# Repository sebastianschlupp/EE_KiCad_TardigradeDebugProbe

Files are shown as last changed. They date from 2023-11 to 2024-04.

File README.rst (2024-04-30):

============
Tardigrade Marine Debug Probe
============

Revision 0.1
============

Required Hand Modifications
~~~~~~~~~~~~~~~~~~~~~~~~~~~

Replace U203 1.8V LDO with 3.3V LDO (LT1962EMS8-1.8 with LT1962EMS8-3.3)

Test Results
------------
  
✅ Voltage outputs OK: VUSB and 1V8

✅ SWD interface OK: connected and successfully erased using J-Link Segger and J-Flash Lite

✅ LEDs OK: VBUS; DBG_LED0; DBG_LED1; VCC; TGT_RESET (remark TGT_RESET led is on when reset is high so inactive ... might want to consider inverting LED in the future)

❌ USB interface not working at 1.8V: please see SAMD21 datasheet chapter 37.15: "The operating voltages must be 3.3V (Min. 3.0V, Max. 3.6V)."

✅ USB interface working at 3.3V

✅ Flashing using west and pyOCD working

Planned Design Changes
----------------------

- Replace LT1962-1.8 with a 3.3V regulator. Also look for a cheaper option since the LT part is around 5€
- Check BOM and investigate need for alternatives (optimise for availability and price)

Revision 0.2
============

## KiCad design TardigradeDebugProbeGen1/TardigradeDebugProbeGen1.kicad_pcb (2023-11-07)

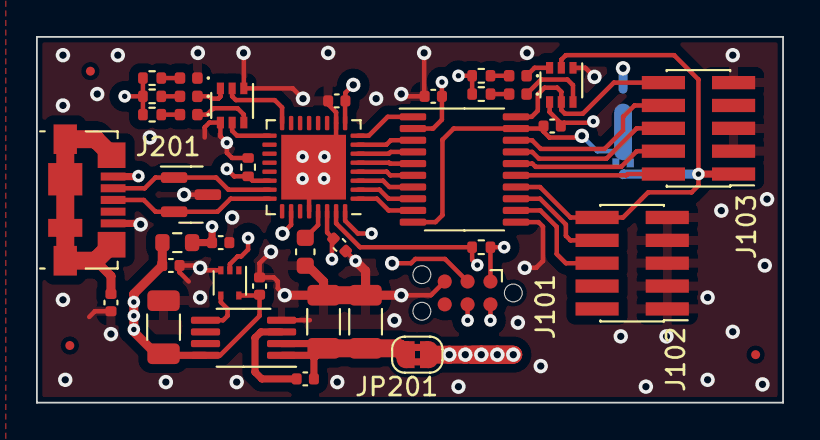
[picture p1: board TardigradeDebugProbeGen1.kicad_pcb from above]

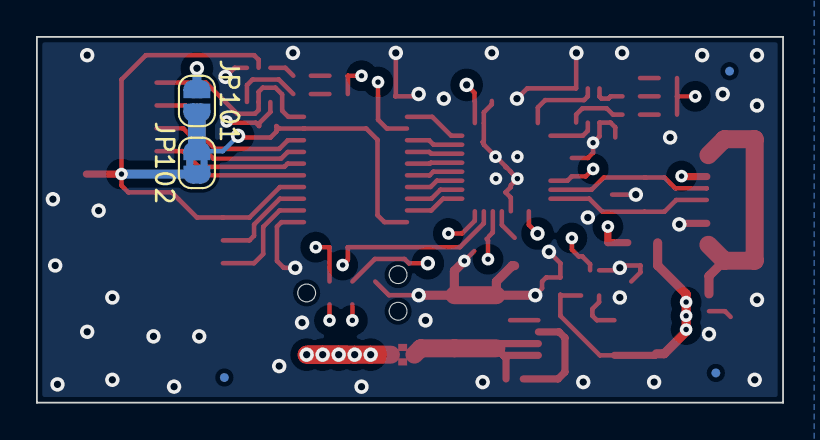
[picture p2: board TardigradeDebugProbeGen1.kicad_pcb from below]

Board: 6 copper layers, 41.5 x 20.3 mm, 46 parts (5 on the bottom side), 43 nets.

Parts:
C101, C102, C104, C105, C202, C203, C204: 100nF; C_0402_1005Metric
C103: 1uF; C_0603_1608Metric
C201: 4.7nF; C_0402_1005Metric
C205, C207, C208: 10uF; C_1206_3216Metric
C206: 10nF; C_0402_1005Metric
D101, D102: YELLOW; LED_0402_1005Metric
D103: RED; LED_0402_1005Metric
D104: GREEN; LED_0402_1005Metric
D201: LED; LED_0402_1005Metric
D202: SP0502BAHT; SOT-23
FB201: FerriteBead; R_0603_1608Metric
FID1, FID2, FID3, FID4, FID5, FID6: Fiducial; Fiducial_0.5mm_Mask1mm
J101: Conn_ARM_SWD_TagConnect_TC2030-NL; Tag-Connect_TC2030-IDC-NL_2x03_P1.27mm_Vertical
J102: Conn_02x05_Odd_Even; PinHeader_2x05_P1.27mm_Vertical_SMD
J103: Conn_ARM_JTAG_SWD_10; PinHeader_2x05_P1.27mm_Vertical_SMD
J201: USB_B_Micro; USB_Micro-B_Molex_47346-0001
JP101: SolderJumper_2_Open; SolderJumper-2_P1.3mm_Open_RoundedPad1.0x1.5mm
JP102, JP201: SolderJumper_2_Bridged; SolderJumper-2_P1.3mm_Bridged2Bar_RoundedPad1.0x1.5mm
Q101, Q102: ADC114; SOT-363_SC-70-6
R101, R102: 1k; R_0402_1005Metric
R103, R104, R105: 150; R_0402_1005Metric
R106, R201: 470; R_0402_1005Metric
U101: ATSAMD21E18A-M; QFN-32-1EP_5x5mm_P0.5mm_EP3.6x3.6mm
U102: TXS0108EPW; TSSOP-20_4.4x6.5mm_P0.65mm
U202: SN74LVC1G14DRL; SOT-553
U203: LT1962-1.8; MSOP-8_3x3mm_P0.65mm

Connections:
+1V8: C101.1, C102.1, C104.1, J101.1 (VCC), JP101.1 (A), JP201.2 (B), R101.2, U101.9 (VDDANA), U101.30 (VDDIN), U102.2 (VCCA)
/DBG_LED0: Q101.2 (B1), U101.16 (PA15)
/DBG_LED1: Q101.5 (B2), U101.17 (PA16)
/DBG_UART_RXD: J102.8, U102.13 (B7)
/DBG_UART_TXD: J102.6, U102.12 (B8)
/MCU_HARAKIRI: R102.2, U101.22 (PA23), U202.2
/SERCOM0_PAD1_SWO: U101.6 (PA05), U102.4 (A3)
/SERCOM1_PAD0_UART_TXD: U101.1 (PA00), U102.9 (A8)
/SERCOM1_PAD1_UART_RXD: U101.2 (PA01), U102.8 (A7)
/USB/USB_D+: D202.2 (K), J201.3 (D+), U101.24 (PA25)
/USB/USB_D-: D202.1 (K), J201.2 (D-), U101.23 (PA24)
GNDREF: C101.2, C102.2, C103.2, C104.2, C105.2, C201.1, C202.2, C203.2, C204.2, C205.2, C207.2, C208.2, D201.1 (K), D202.3 (A), J101.5 (GND), J102.1, J102.3, J102.5, J102.7, J102.9, J103.3 (GND), J103.5 (GND), J103.9 (GNDDetect), J201.5 (GND), Q101.1 (E1), Q101.4 (E2), Q102.1 (E1), Q102.4 (E2), R102.1, U101.10 (GND), U101.28 (GND), U101.33 (EP), U102.11 (GND), U202.3 (GND), U203.4 (GND)
unnamed: D101.2 (A), R103.1
unnamed: D101.1 (K), Q101.6 (C1)
unnamed: D102.2 (A), R104.1
unnamed: D102.1 (K), Q101.3 (C2)
unnamed: D103.2 (A), R105.1
unnamed: D103.1 (K), Q102.3 (C2)
unnamed: D104.2 (A), R106.1
unnamed: D104.1 (K), Q102.6 (C1)
unnamed: D201.2 (A), R201.1
unnamed: J101.4 (SWCLK), R101.1, U101.31 (PA30)
unnamed: J101.2 (SWDIO), U101.32 (PA31)
unnamed: J101.3 (~RESET), U101.26 (~RESET)
unnamed: J103.8 (NC/TDI), U102.18 (B2)
unnamed: J103.4 (SWDCLK/TCK), U102.16 (B4)
unnamed: J103.2 (SWDIO/TMS), U102.15 (B5)
unnamed: J103.6 (SWO/TDO), U102.17 (B3)
unnamed: C201.2, J201.6 (Shield)
unnamed: C203.1, FB201.1, J201.1 (VBUS)
unnamed: C105.1, JP101.2 (B), JP102.2 (B), U102.10 (OE), U102.19 (VCCB)
unnamed: C206.2, C207.1, C208.1, JP201.1 (A), U203.1 (OUT), U203.2 (SENSE)
unnamed: U101.3 (PA02), U102.7 (A6)
unnamed: U101.4 (PA03), U102.6 (A5)
unnamed: U101.5 (PA04), U102.5 (A4)
unnamed: U101.7 (PA06), U102.3 (A2)
unnamed: U101.8 (PA07), U102.1 (A1)
unnamed: C103.1, U101.29 (VDDCORE)
unnamed: C206.1, U203.3 (BYP)
unnamed: U202.4, U203.5 (~SHDN)
TGT_~RST: J103.10 (~RESET), Q102.5 (B2), U102.20 (B1)
VBUS: C202.1, C204.1, C205.1, FB201.2, R103.2, R104.2, R105.2, R106.2, R201.2, U202.5 (VCC), U203.8 (IN)
VCC: J102.10, J103.1 (VTref), JP102.1 (A), Q102.2 (B1), U102.14 (B6)
